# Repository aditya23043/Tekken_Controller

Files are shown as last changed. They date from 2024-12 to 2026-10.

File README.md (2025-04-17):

# One Handed Controller for playing games

- Currently targeting right handed controller and for Tekken because it needs lesser buttons than games like GTA V or CS GO

## Prototype 1

- All files are inside the `prototype_1/` directory

### Shortcomings

- Screw mounting holes are not in the correct place in the bottom plate
- The gap between adjacent switches is not large enough for the keycaps to fit in

### Learnings

- Metal standoffs are enough to hold the top plate rigidly without any visible bending

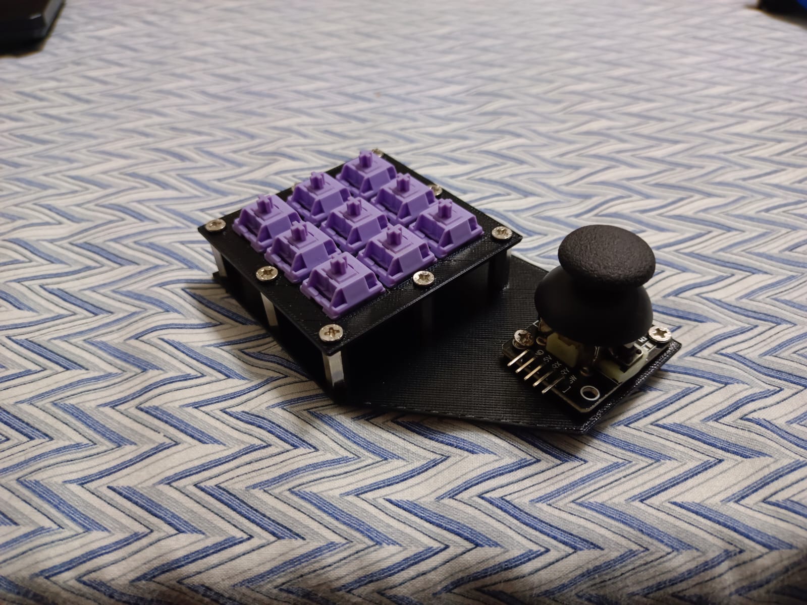
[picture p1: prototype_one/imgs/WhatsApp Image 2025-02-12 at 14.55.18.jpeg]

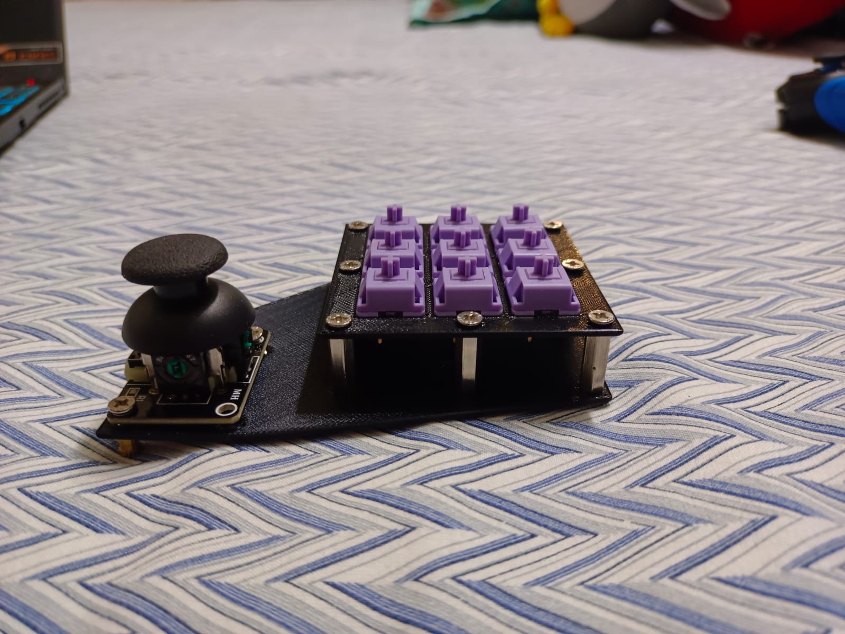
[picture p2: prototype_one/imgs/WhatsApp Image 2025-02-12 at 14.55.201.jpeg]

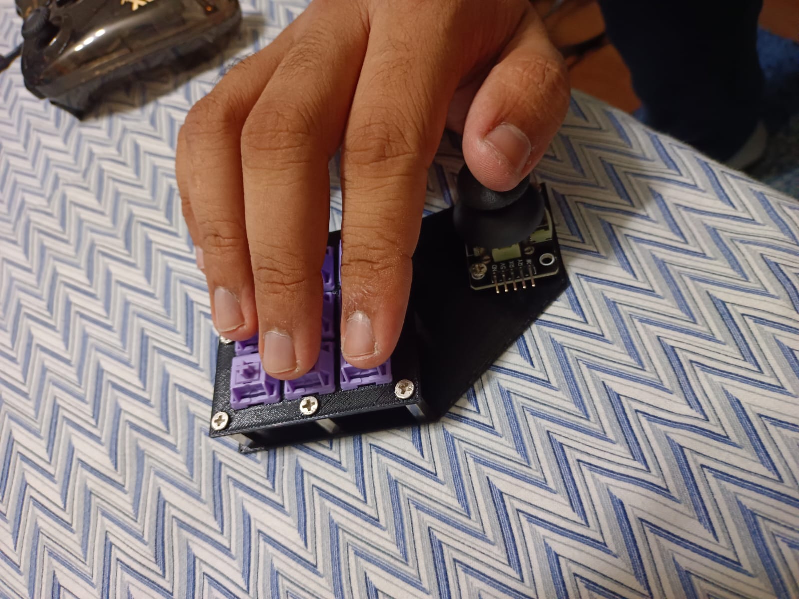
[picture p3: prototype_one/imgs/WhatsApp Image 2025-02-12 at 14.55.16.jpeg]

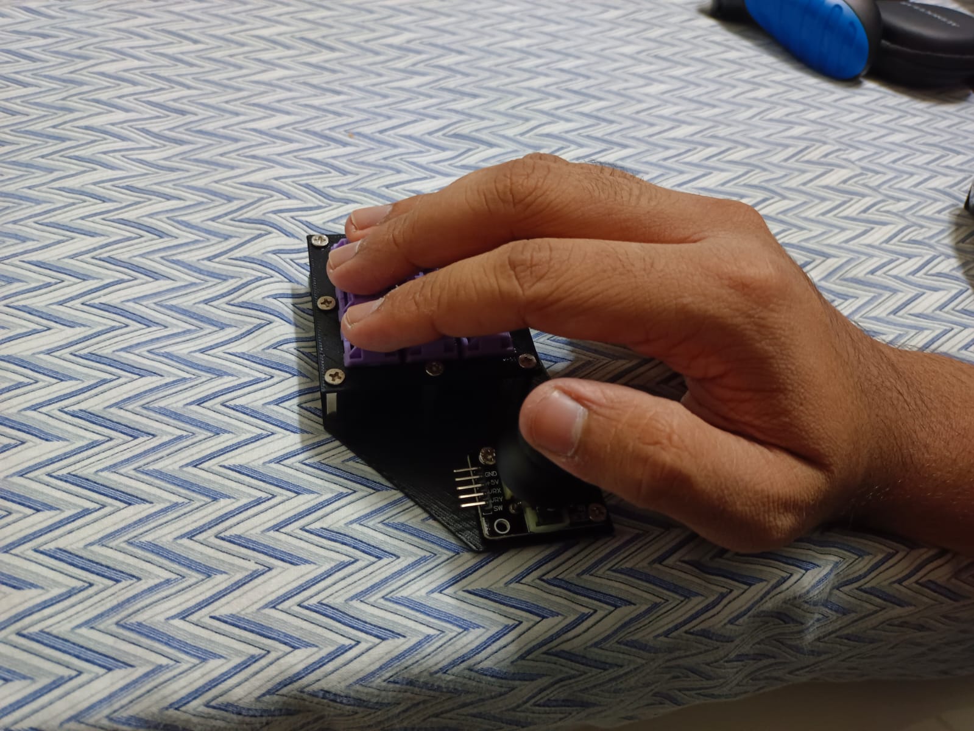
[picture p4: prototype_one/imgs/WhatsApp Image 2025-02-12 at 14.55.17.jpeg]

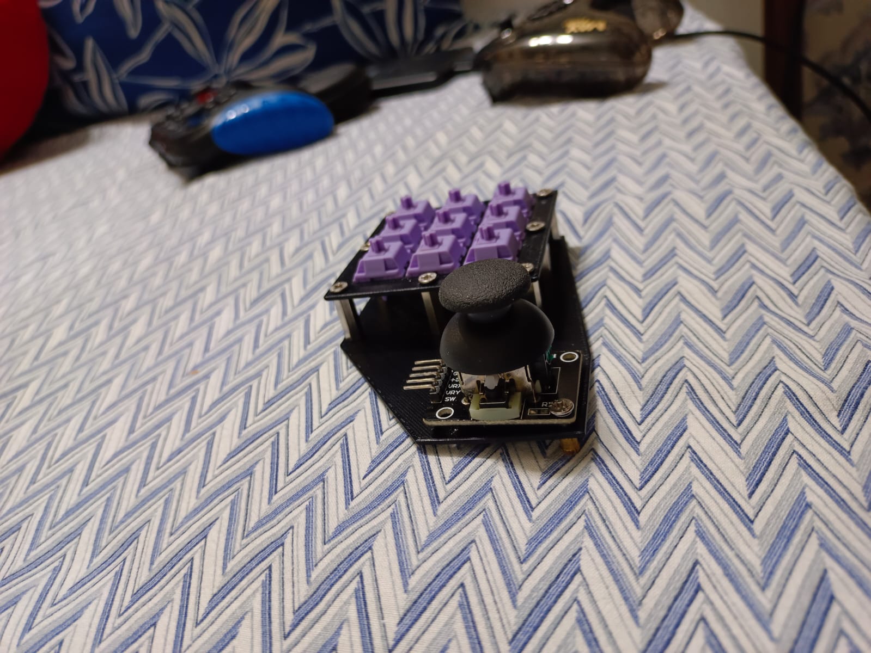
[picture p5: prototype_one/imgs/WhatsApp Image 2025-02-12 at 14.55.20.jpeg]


## Prototype 3

- Switched from a 3x3 switch matrix to a 4x3 switch matrix
- Added dedicated mounting holes for the microcontroller
- Corrected the positioning of the analog joystick and the gap between adjacent MX switches

### Order

- Switch Mount plate : Rs. 74 (PLA - black)
- Bottom Plate - Rs. 122 : PLA - black - 1.5mm - Rs. 149 : Mild Steel - 1mm - Rs. 167 : Mild Steel - 2mm - Rs. 112 : ABS black - 2mm - Rs. 122 : ABS black - 3mm (this is the one I will be ordering) - Rs. 104 : Transparent Acrylic - 2mm - Rs. 263 : Stainless Steel 304 - 1mm

> Note: I have switched the bottom plate a little bit so that a raspberry pi pico could be mounted on the bottom plate so, the price could be a bit skewed, just ~5/6rs

### Final BOM

- Bottom plate -> ABS (non metal laser cut) 3mm -> Rs. 129 + taxes = Rs. 178 (ordered)
- Mount plate -> ABS (PLA 3d printed) -> Rs. 79 + taxes (ordered alongside the single case for -> https://github.com/aditya23043/split36)

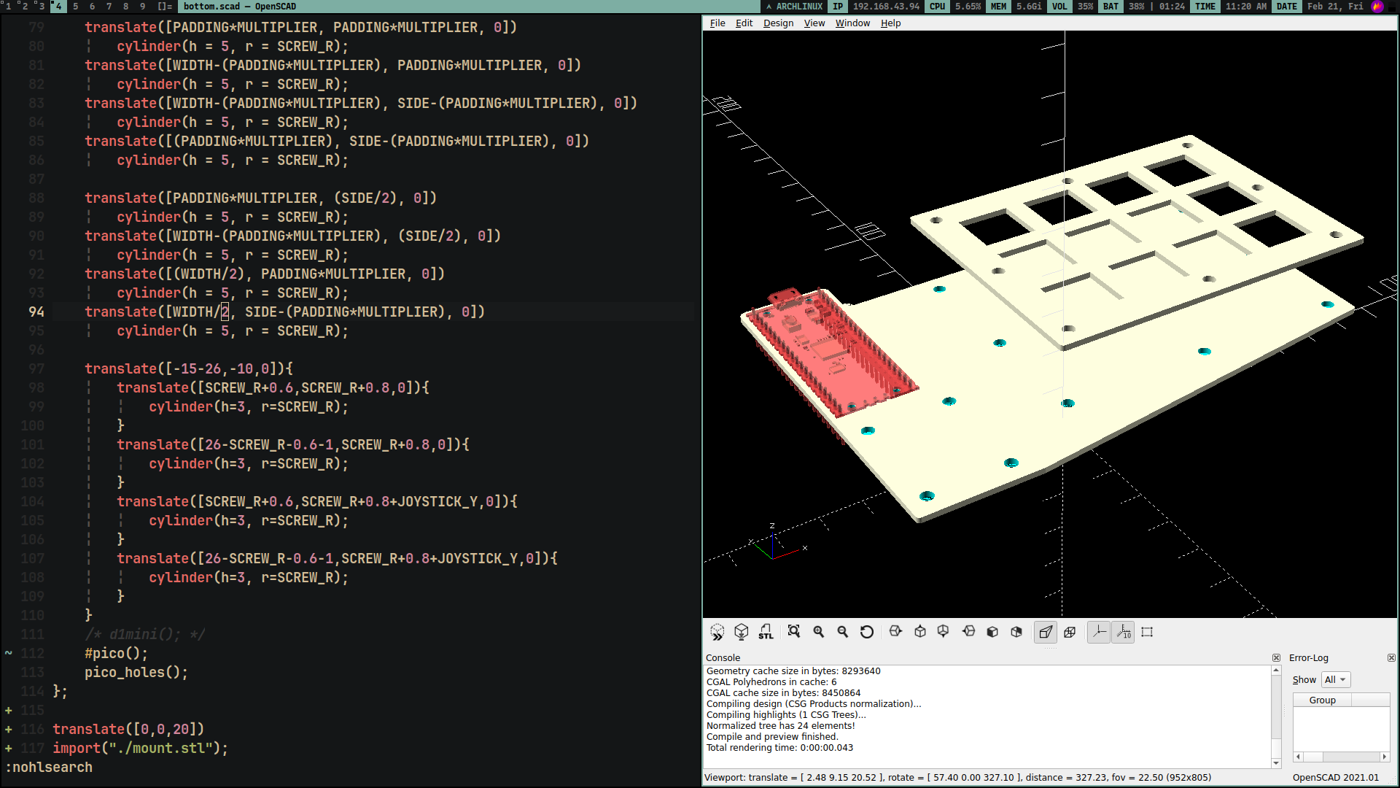
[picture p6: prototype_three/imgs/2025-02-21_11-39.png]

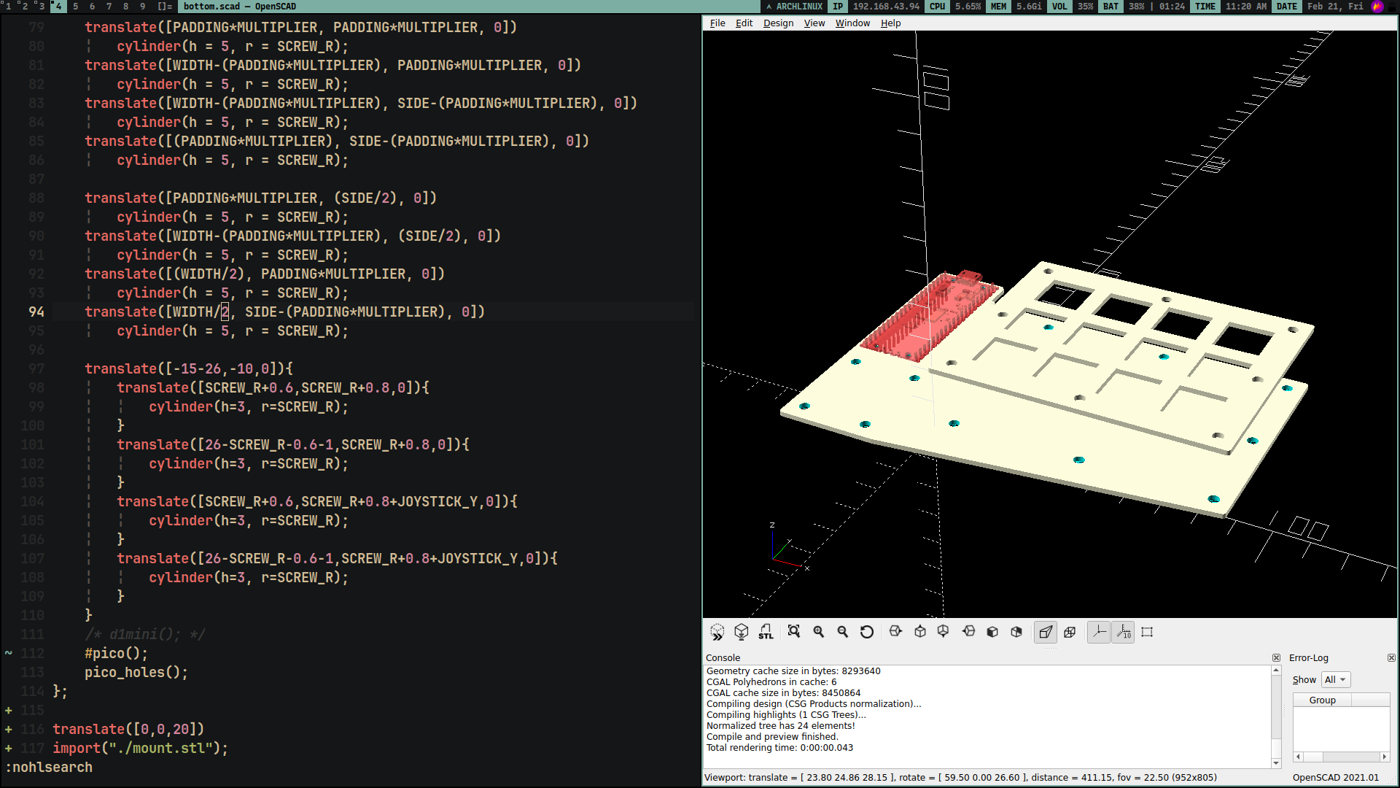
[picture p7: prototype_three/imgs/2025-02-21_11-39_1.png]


### 2025-02-26 23:48

- Finally, all the materials have arrived (I was waiting for the case only. I already had all of the other stuff in my inventory)
- Furthermore, I have assembled all the materials as well

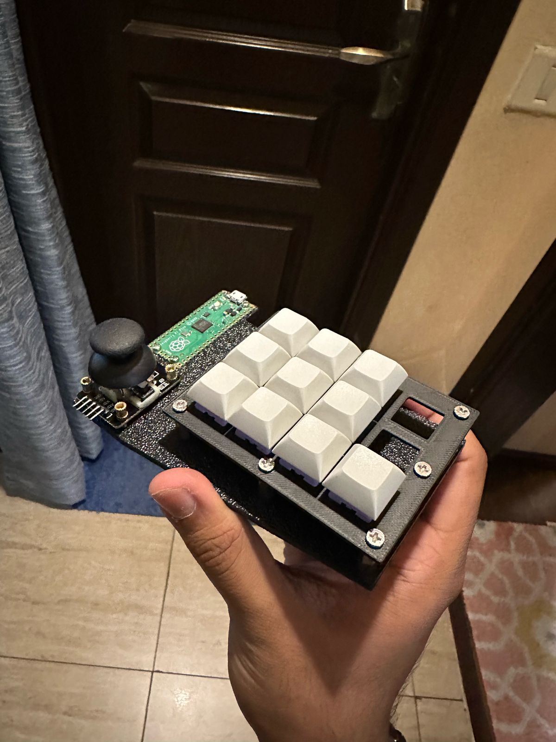
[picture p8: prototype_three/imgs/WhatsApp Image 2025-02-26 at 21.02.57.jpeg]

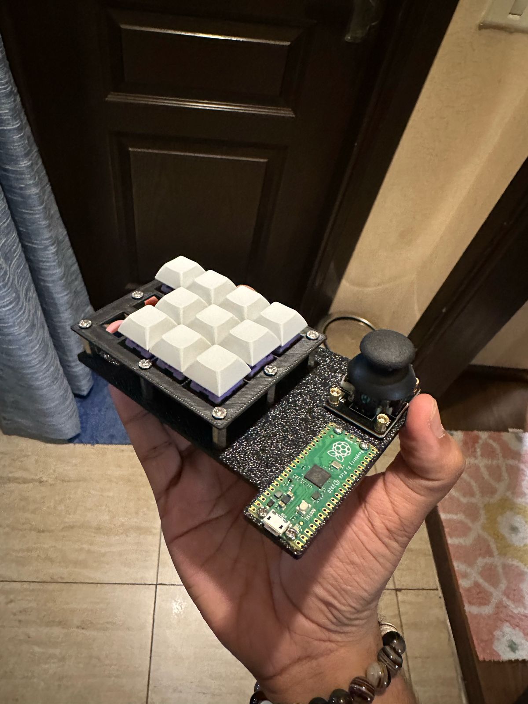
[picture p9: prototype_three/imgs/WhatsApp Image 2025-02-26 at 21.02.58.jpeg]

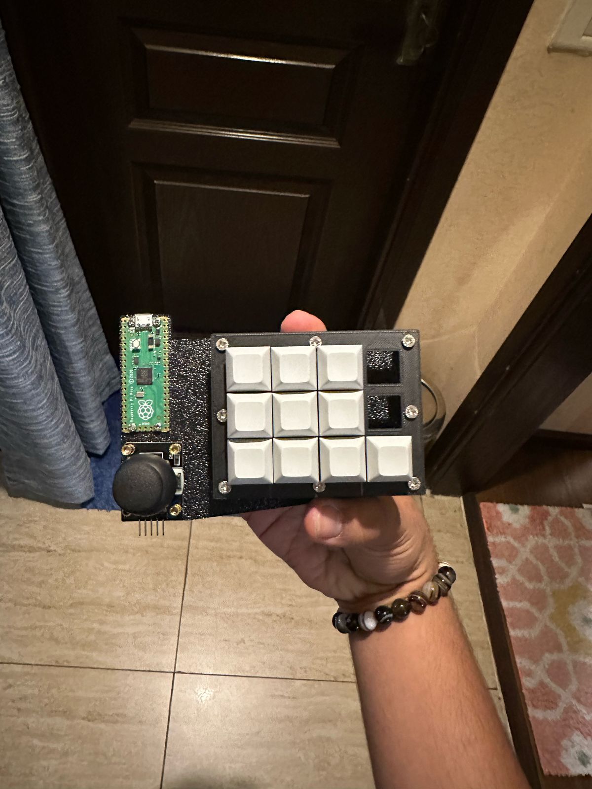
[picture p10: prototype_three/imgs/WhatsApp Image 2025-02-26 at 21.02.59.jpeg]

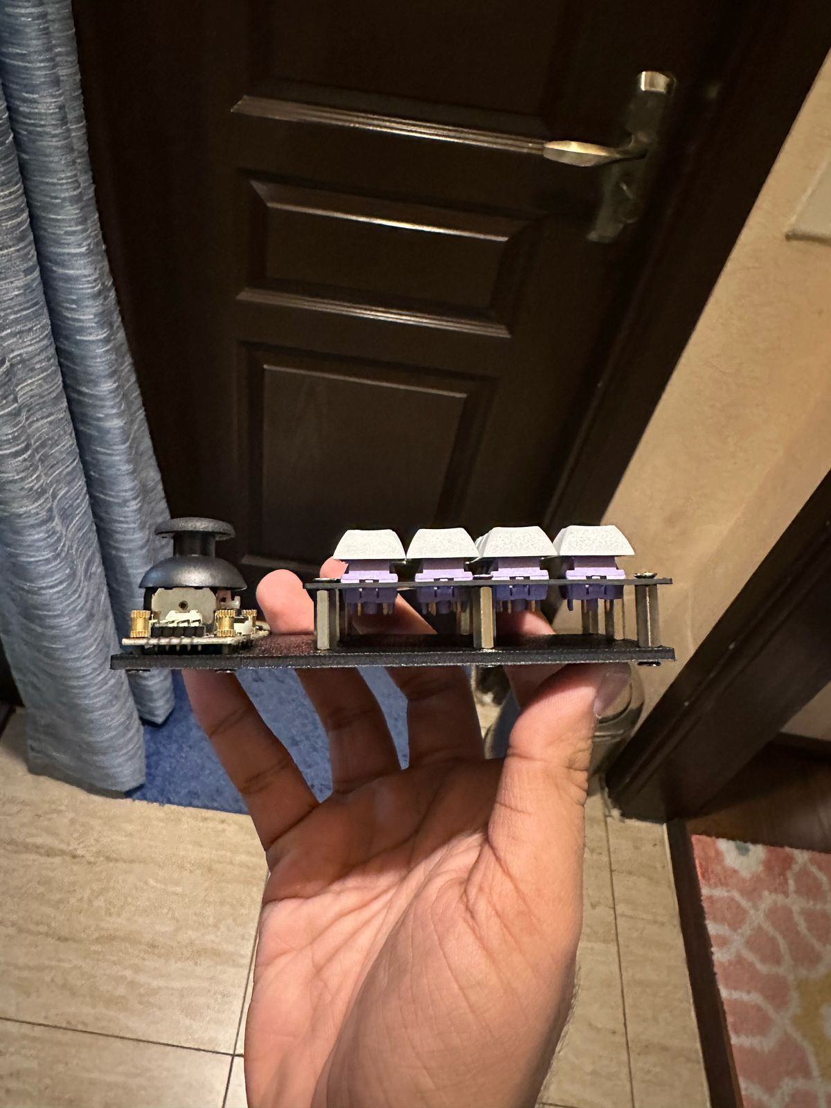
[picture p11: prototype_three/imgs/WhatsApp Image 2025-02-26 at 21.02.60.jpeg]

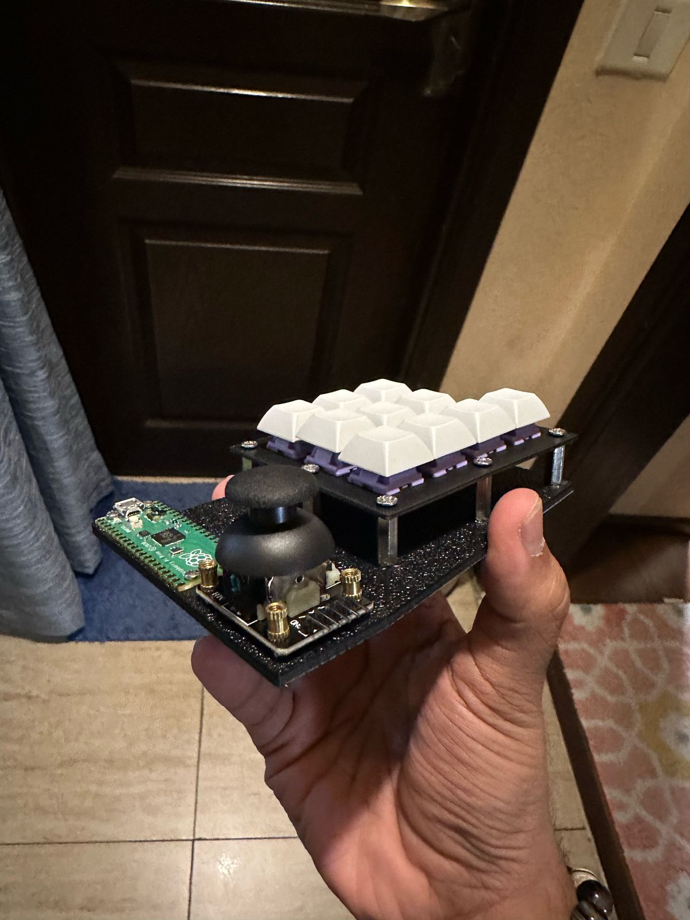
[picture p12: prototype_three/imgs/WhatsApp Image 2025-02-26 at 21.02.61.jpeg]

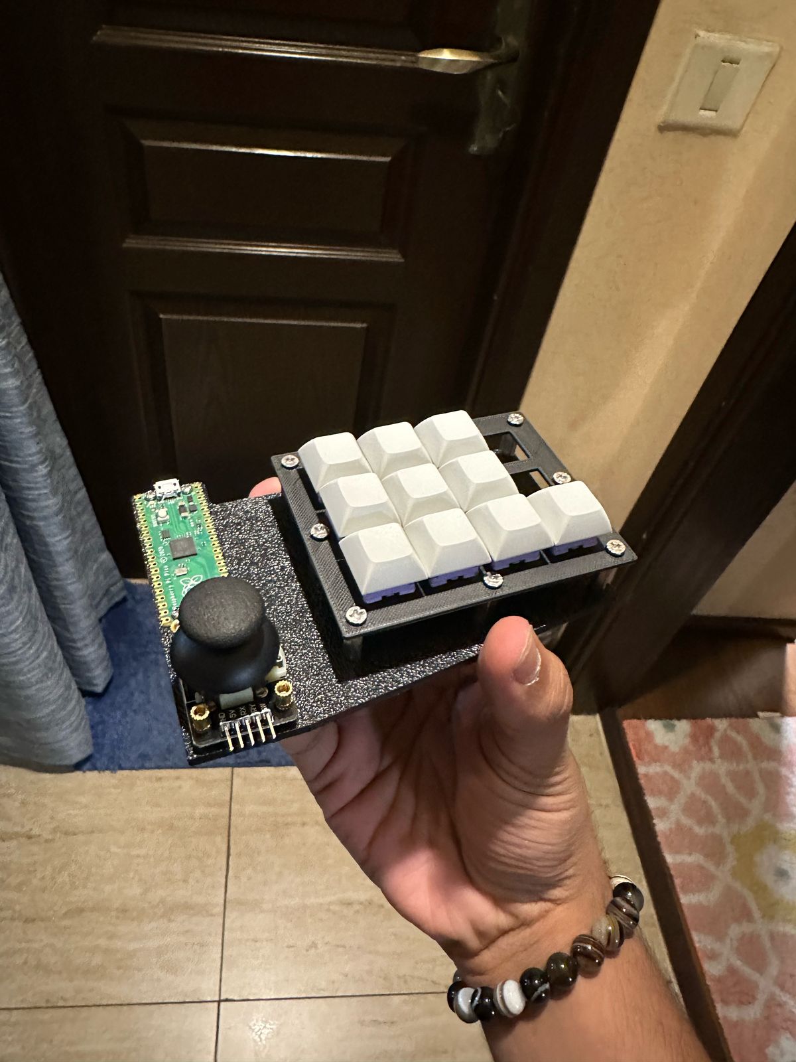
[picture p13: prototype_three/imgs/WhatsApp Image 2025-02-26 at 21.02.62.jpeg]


> Note that you only see 10 out of the 12 switches attached because I only had these 10 switches laying around from my HMX hyacinth V2U collection. The rest 20 were placed in the [20 Key Split Keyboard](https://github.com/aditya23043/split_keyboard) out of the 30 I had ordered

- Since two of my mid semester exams are still remaining (PSD and F&W), I will be waiting for them to get over before beginning with the firmware

### 2025-04-18 00:16
- Wiring and all of the hardware part completed
- Firmware development begins from tomorrow
- [ ] Todo: I would like to add some kind of combination of keys to switch to different keymaps corresponding to different gammes

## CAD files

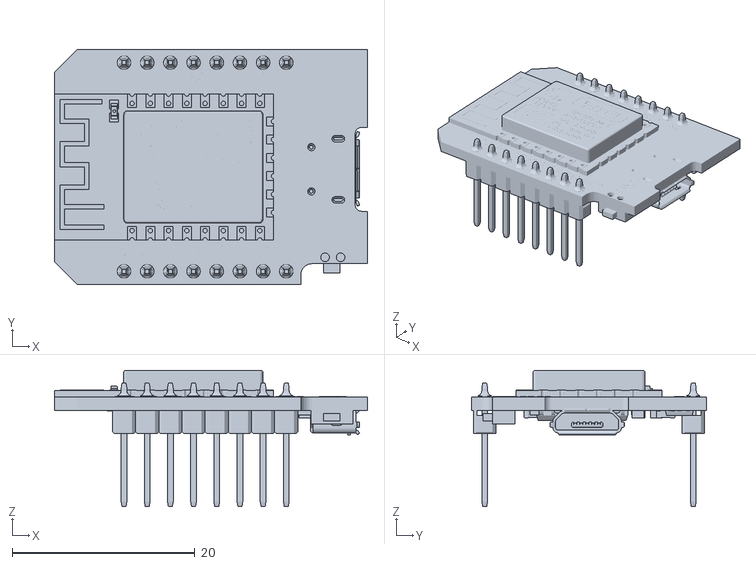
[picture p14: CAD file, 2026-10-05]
prototype_three/WEMOS-MINI-D1_ASM (Meshed).stl
34.3 x 25.8 x 14.9

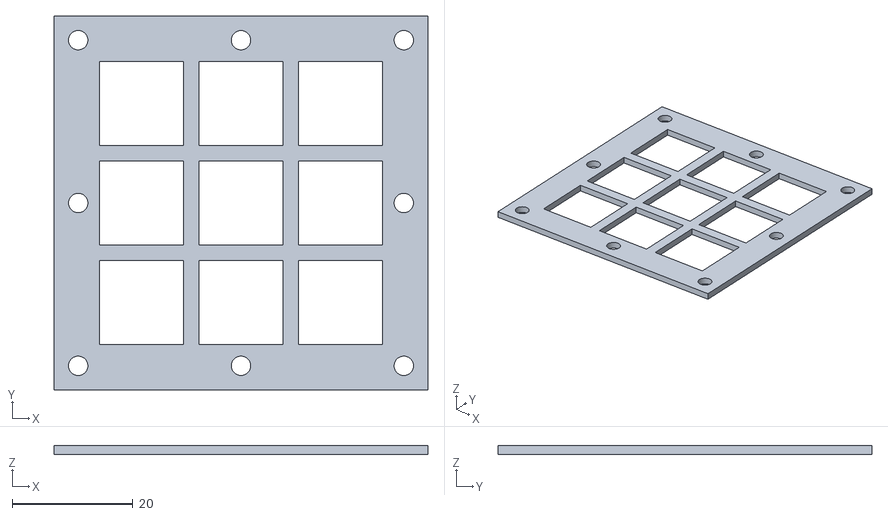
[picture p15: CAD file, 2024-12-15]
prototype_one/top.stl
61.8 x 61.8 x 1.50

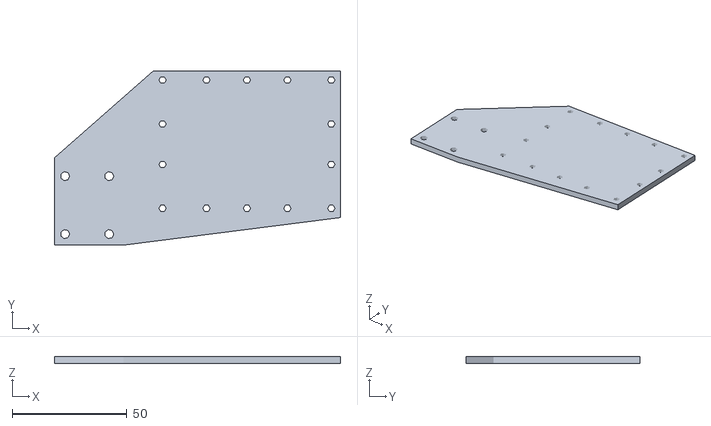
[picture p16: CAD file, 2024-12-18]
prototype_two/bottom.stl
124.4 x 75.8 x 3.00

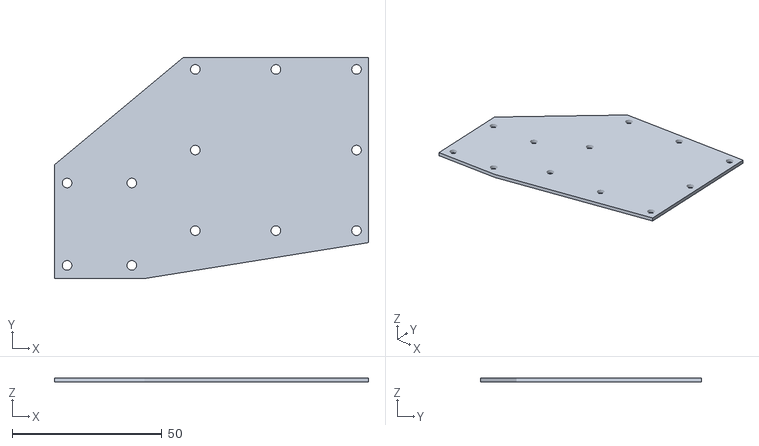
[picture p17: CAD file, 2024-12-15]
prototype_one/bottom.stl
104.8 x 73.8 x 1.50

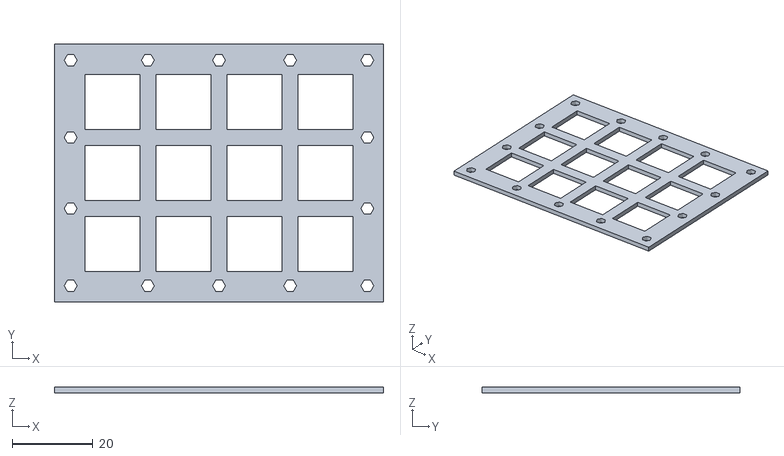
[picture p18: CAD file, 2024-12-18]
prototype_two/top.stl
81.4 x 63.8 x 1.50

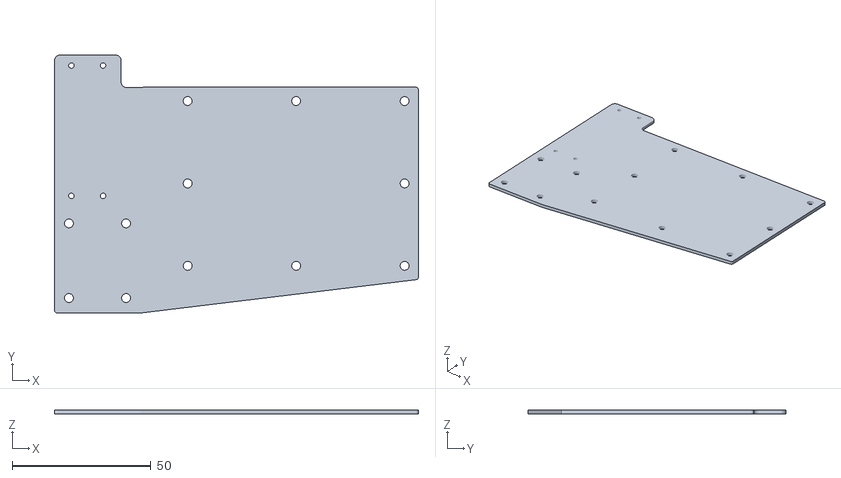
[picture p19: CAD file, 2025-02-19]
prototype_three/bottom_with_pico.stl
131.2 x 93.0 x 1.50

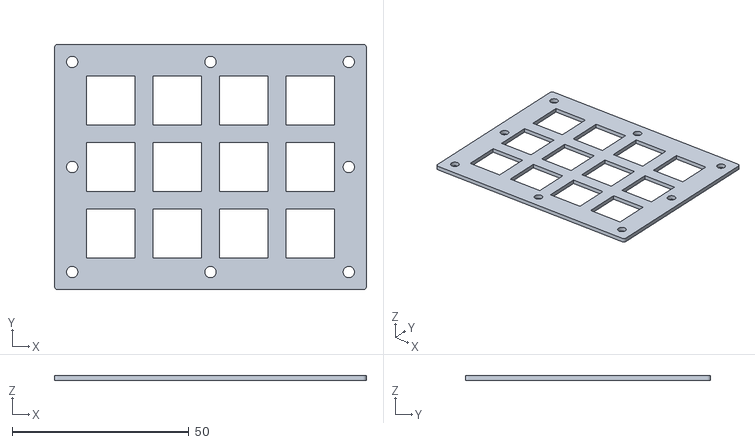
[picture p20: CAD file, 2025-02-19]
prototype_three/mount.stl
88.2 x 69.4 x 1.50

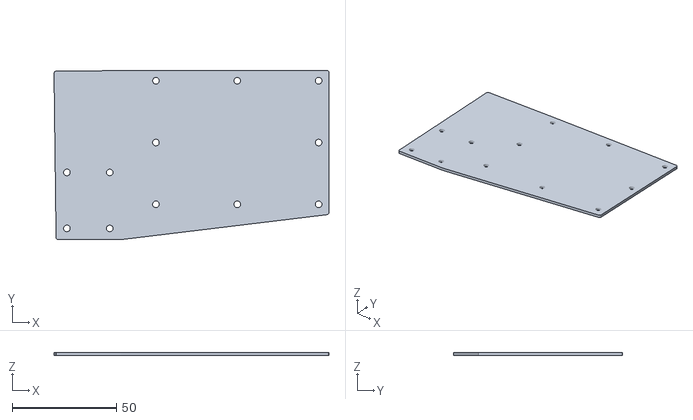
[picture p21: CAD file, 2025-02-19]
prototype_three/bottom.stl
132.2 x 81.4 x 1.50

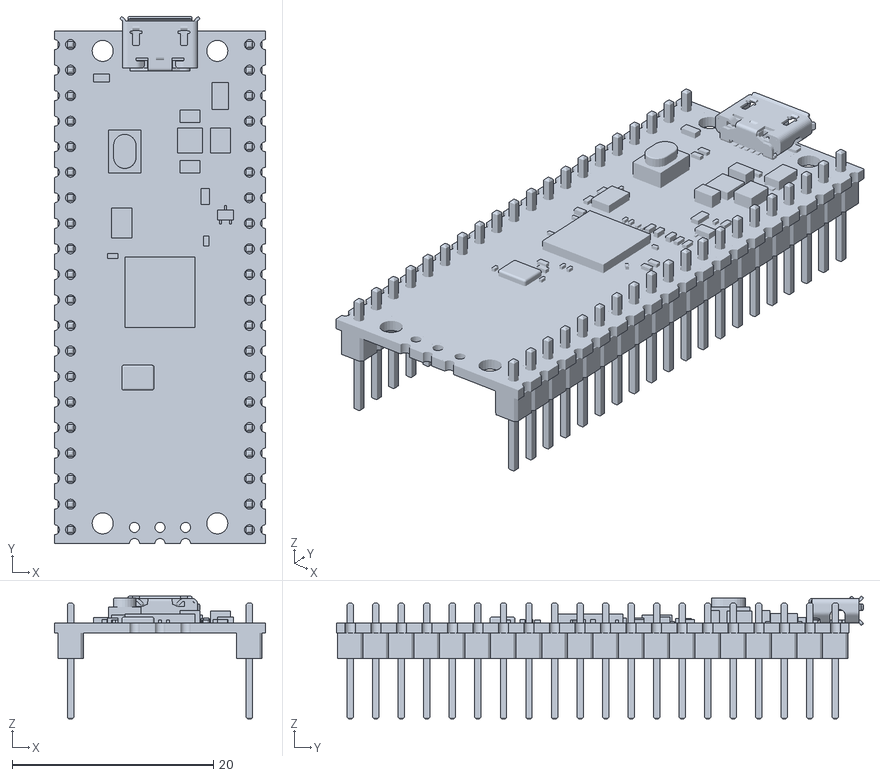
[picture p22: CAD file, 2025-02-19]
prototype_three/rpi.stl
21.0 x 52.4 x 12.2

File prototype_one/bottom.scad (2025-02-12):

SIDE = 51.82;
PAD = 2.53;
SWITCH = 13.9;
PADDING = 10;
SCREW_R = 1.6;
$fn=100;

// total padding = 2.53+5

/* linear_extrude(1.5) */

difference(){

	hull(){
		square([SIDE+PADDING, SIDE+PADDING]);
		translate([-2-15-26,-2-10,0]){
			square([26+4, 34+4]);
		}
	}

	#translate([4,4,0]){
		circle(r=SCREW_R);
	}
	translate([SIDE+PADDING-4,4,0]){
		circle(r=SCREW_R);
	}
	translate([4,SIDE+PADDING-4,0]){
		circle(r=SCREW_R);
	}
	translate([SIDE+PADDING-4,SIDE+PADDING-4,0]){
		circle(r=SCREW_R);
	}
	#translate([4, (SIDE+PADDING)/2, 0]){
		circle(r=SCREW_R);
	}
	translate([SIDE+PADDING-4, (SIDE+PADDING)/2, 0]){
		circle(r=SCREW_R);
	}
	translate([(SIDE+PADDING)/2, 4, 0]){
		circle(r=SCREW_R);
	}
	translate([(SIDE+PADDING)/2, SIDE+PADDING-4, 0]){
		circle(r=SCREW_R);
	}

	translate([-15-26,-10,0]){
		translate([SCREW_R+0.6,SCREW_R+0.8,0]){
			circle(r=SCREW_R);
		}
		translate([26-SCREW_R-0.6,SCREW_R+0.8,0]){
			circle(r=SCREW_R);
		}
		translate([SCREW_R+0.6,34-SCREW_R-2.5,0]){
			circle(r=SCREW_R);
		}
		translate([26-SCREW_R-0.6,34-SCREW_R-2.5,0]){
			circle(r=SCREW_R);
		}
	}
}

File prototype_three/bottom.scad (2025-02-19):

$fn=100;

SCREW_R = 1.6;
PADDING = 8;
MX_SIDE = 13.8;
MX_GAP = 5;
SIDE = (2*PADDING)+(3*MX_SIDE)+(2*MX_GAP);
WIDTH = SIDE + MX_GAP + MX_SIDE;
MULTIPLIER = 0.5;
JOYSTICK_Y = ((51.82+10) / 2)-4;

module d1mini() {
    color("#ffffff")
    rotate([0,0,90])
    translate([50,22,5])
    #import("WEMOS-MINI-D1_ASM (Meshed).stl");
}

module pico(){
    color("#ffffff")
    translate([-128,100,-3])
    import("rpi.stl");
}

module pico_holes(){
    translate([-29.9-8,29.2,0])
            cylinder(r=1,h=2);
    translate([-18.5-8,29.2,0])
            cylinder(r=1,h=2);
    translate([-29.9-8,76.2,0])
            cylinder(r=1,h=2);
    translate([-18.5-8,76.2,0])
            cylinder(r=1,h=2);
}

// projection()
difference(){
    
    union(){
        hull(){
            minkowski(){
                cube([WIDTH, SIDE, 1.4]);
                cylinder(r=1, h=0.1);
            }
            minkowski(){
                linear_extrude(1.4)
                translate([-2-15-26,-2-10,0]){
                    square([26+4, 34+4]);
                }
                cylinder(r=1, h=0.1);
            }
            translate([-44,66.3,0])
                cube([2,2,1.5]);
                /* cylinder(r=1,h=1.5); */
        }
        minkowski(){
            translate([-43+1,68,0])
                cube([10+10+1-1, 10, 1.4]);
            cylinder(r=2,h=0.1);
        }
        
        intersection(){

            difference(){
                translate([-18,70.3,0])
                    translate([-2,-2,0])
                    cube([4,4,1.5]);
                translate([-18,70.3,0])
                    cylinder(h=1.5,r=2);
            };
            translate([-2,-2,0])
                translate([-18,70.3,0])
                cylinder(h=1.5,r=2);
        };

    };

    // screw holes
    translate([PADDING*MULTIPLIER, PADDING*MULTIPLIER, 0])
        cylinder(h = 5, r = SCREW_R);
    translate([WIDTH-(PADDING*MULTIPLIER), PADDING*MULTIPLIER, 0])
        cylinder(h = 5, r = SCREW_R);
    translate([WIDTH-(PADDING*MULTIPLIER), SIDE-(PADDING*MULTIPLIER), 0])
        cylinder(h = 5, r = SCREW_R);
    translate([(PADDING*MULTIPLIER), SIDE-(PADDING*MULTIPLIER), 0])
        cylinder(h = 5, r = SCREW_R);

    translate([PADDING*MULTIPLIER, (SIDE/2), 0])
        cylinder(h = 5, r = SCREW_R);
    translate([WIDTH-(PADDING*MULTIPLIER), (SIDE/2), 0])
        cylinder(h = 5, r = SCREW_R);
    translate([(WIDTH/2), PADDING*MULTIPLIER, 0])
        cylinder(h = 5, r = SCREW_R);
    translate([WIDTH/2, SIDE-(PADDING*MULTIPLIER), 0])
        cylinder(h = 5, r = SCREW_R);

    translate([-15-26,-10,0]){
        translate([SCREW_R+0.6,SCREW_R+0.8,0]){
            cylinder(h=3, r=SCREW_R);
        }
        translate([26-SCREW_R-0.6-1,SCREW_R+0.8,0]){
            cylinder(h=3, r=SCREW_R);
        }
        translate([SCREW_R+0.6,SCREW_R+0.8+JOYSTICK_Y,0]){
            cylinder(h=3, r=SCREW_R);
        }
        translate([26-SCREW_R-0.6-1,SCREW_R+0.8+JOYSTICK_Y,0]){
            cylinder(h=3, r=SCREW_R);
        }
    }
    /* d1mini(); */
    /* #pico(); */
    pico_holes();
};

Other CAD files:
prototype_three/wemos-mini-d1.stp
prototype_three/wemos.stl
prototype_one/top.scad
prototype_three/mount.scad
prototype_one/bottom.dxf
prototype_three/bottom.dxf
prototype_three/bottom_with_pico.dxf
prototype_two/bottom.dxf
prototype_two/bottom.scad
prototype_two/top.scad

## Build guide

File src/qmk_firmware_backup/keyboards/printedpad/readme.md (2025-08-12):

# Printed Pad

magtray4x3

* Keyboard Maintainer: [noahbei](https://github.com/noahbei)
* Hardware Supported: STM32F072RBT6
* Hardware Availability: https://protadesigns.com/products/printed-pad

Make example for this keyboard (after setting up your build environment):

    make printedpad:default

Flashing example for this keyboard:

    make printedpad:default:flash

See the [build environment setup](https://docs.qmk.fm/#/getting_started_build_tools) and the [make instructions](https://docs.qmk.fm/#/getting_started_make_guide) for more information. Brand new to QMK? Start with our [Complete Newbs Guide](https://docs.qmk.fm/#/newbs).

## Bootloader

Enter the bootloader in 3 ways:

* **Bootmagic reset**: Hold down the key at (0,0) in the matrix (usually the top left key or Escape) and plug in the keyboard
* **Physical reset button**: Briefly press the button on the back of the PCB - some may have pads you must short instead
* **Keycode in layout**: Press the key mapped to `QK_BOOT` if it is available

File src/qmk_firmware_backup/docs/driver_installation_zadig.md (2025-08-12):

# Bootloader Driver Installation with Zadig

QMK presents itself to the host as a regular HID keyboard device, and as such requires no special drivers. However, in order to flash your keyboard on Windows, the bootloader device that appears when you reset the board often *does*.

There are two notable exceptions: the Caterina bootloader, usually seen on Pro Micros, and the HalfKay bootloader shipped with PJRC Teensys, appear as a serial port and a generic HID device respectively, and so do not require a driver.

We recommend the use of the [Zadig](https://zadig.akeo.ie/) utility. If you have set up the development environment with MSYS2, the `qmk_install.sh` script will have already installed the drivers for you.

## Installation

Put your keyboard into bootloader mode, either by hitting the `QK_BOOT` keycode (which may be on a different layer), or by pressing the reset switch that's usually located on the underside of the board. If your keyboard has neither, try holding Escape or Space+`B` as you plug it in (see the [Bootmagic](features/bootmagic) docs for more details). Some boards use [Command](features/command) instead of Bootmagic; in this case, you can enter bootloader mode by hitting Left Shift+Right Shift+`B` or Left Shift+Right Shift+Escape at any point while the keyboard is plugged in.
Some keyboards may have specific instructions for entering the bootloader. For example, the [Bootmagic](features/bootmagic) key (default: Escape) might be on a different key, e.g. Left Control; or the magic combination for Command (default: Left Shift+Right Shift) might require you to hold something else, e.g. Left Control+Right Control. Refer to the board's README file if you are unsure.

To put a device in bootloader mode with USBaspLoader, tap the `RESET` button while holding down the `BOOT` button.
Alternatively, hold `BOOT` while inserting the USB cable.

Zadig should automatically detect the bootloader device, but you may sometimes need to check **Options → List All Devices** and select the device from the dropdown instead.

::: warning
If Zadig lists one or more devices with the `HidUsb` driver, your keyboard is probably not in bootloader mode. The arrow will be colored orange and you will be asked to confirm modifying a system driver. **Do not** proceed if this is the case!
:::

If the arrow appears green, select the driver, and click **Install Driver**. See the [list of known bootloaders](#list-of-known-bootloaders) for the correct driver to install.

Zadig with a bootloader driver correctly installed

Finally, unplug and replug the keyboard to make sure the new driver has been loaded. If you are using the QMK Toolbox to flash, exit and restart it too, as it can sometimes fail to recognize the driver change.

## Recovering from Installation to Wrong Device

If you find that you can no longer type with the keyboard, you may have accidentally replaced the driver for the keyboard itself instead of for the bootloader. This can happen when the keyboard is not in the bootloader mode. You can easily confirm this in Zadig - a healthy keyboard has the `HidUsb` driver installed on all of its interfaces:

A healthy keyboard as seen by Zadig

Open the Device Manager, select **View → Devices by container**, and look for an entry with your keyboard's name.

The board with the wrong driver installed, in Device Manager

Right-click each entry and hit **Uninstall device**. Make sure to tick **Delete the driver software for this device** first if it appears.

The Device Uninstall dialog, with the "delete driver" checkbox ticked

Click **Action → Scan for hardware changes**. At this point, you should be able to type again. Double check in Zadig that the keyboard device(s) are using the `HidUsb` driver. If so, you're all done, and your board should be functional again! Otherwise, repeat this process until Zadig reports the correct driver.

::: tip
A full reboot of your computer may sometimes be necessary at this point, to get Windows to pick up the new driver.
:::

## Uninstallation

Uninstallation of bootloader devices is a little more involved than installation.

Open the Device Manager, select **View → Devices by container**, and look for the bootloader device. Match up the USB VID and PID in Zadig with one from [the table below](#list-of-known-bootloaders).

Find the `Inf name` value in the Details tab of the device properties. This should generally be something like `oemXX.inf`:

Device properties showing the Inf name value

Then, open a new Command Prompt window as an Administrator (type in `cmd` into the Start menu and press Ctrl+Shift+Enter). Run `pnputil /enum-drivers` to verify the `Inf name` matches the `Published Name` field of one of the entries:

pnputil output with matching driver highlighted

Run `pnputil /delete-driver oemXX.inf /uninstall`. This will delete the driver and remove it from any devices using it. Note that this will not uninstall the device itself.

As with the previous section, this process may need to be repeated multiple times, as multiple drivers can be applicable to the same device.

::: warning
Be *extremely careful* when doing this! You could potentially uninstall the driver for some other critical device. If you are unsure, double check the output of `/enum-drivers`, and omit the `/uninstall` flag when running `/delete-driver`.
:::

## List of Known Bootloaders

This is a list of known bootloader devices and their USB vendor and product IDs, as well as the correct driver to assign for flashing with QMK. Note that the usbser and HidUsb drivers are built in to Windows, and cannot be assigned with Zadig - if your device has an incorrect driver, you must use the Device Manager to uninstall it as described in the previous section.

The device name here is the name that appears in Zadig, and may not be what the Device Manager or QMK Toolbox displays.

|Bootloader |Device Name |VID/PID |Driver |
|---|---|---|---|
|`atmel-dfu` |ATmega16u2 DFU |`03EB:2FEF` |WinUSB |
|`atmel-dfu` |ATmega32U2 DFU |`03EB:2FF0` |WinUSB |
|`atmel-dfu` |ATm16U4 DFU V1.0.2 |`03EB:2FF3` |WinUSB |
|`atmel-dfu` |ATm32U4DFU |`03EB:2FF4` |WinUSB |
|`atmel-dfu` |*none* (AT90USB64) |`03EB:2FF9` |WinUSB |
|`atmel-dfu` |AT90USB128 DFU |`03EB:2FFB` |WinUSB |
|`qmk-dfu` |(keyboard name) Bootloader |As `atmel-dfu`|WinUSB |
|`halfkay` |*none* |`16C0:0478` |HidUsb |
|`caterina` |Pro Micro 3.3V |`1B4F:9203` |usbser |
|`caterina` |Pro Micro 5V |`1B4F:9205` |usbser |
|`caterina` |LilyPadUSB |`1B4F:9207` |usbser |
|`caterina` |Pololu A-Star 32U4 Bootloader |`1FFB:0101` |usbser |
|`caterina` |Arduino Leonardo |`2341:0036` |usbser |
|`caterina` |Arduino Micro |`2341:0037` |usbser |
|`caterina` |Adafruit Feather 32u4 |`239A:000C` |usbser |
|`caterina` |Adafruit ItsyBitsy 32u4 3V |`239A:000D` |usbser |
|`caterina` |Adafruit ItsyBitsy 32u4 5V |`239A:000E` |usbser |
|`caterina` |Arduino Leonardo |`2A03:0036` |usbser |
|`caterina` |Arduino Micro |`2A03:0037` |usbser |
|`bootloadhid` |HIDBoot |`16C0:05DF` |HidUsb |
|`usbasploader`|USBasp |`16C0:05DC` |libusbK|
|`apm32-dfu` |APM32 DFU ISP Mode |`314B:0106` |WinUSB |
|`at32-dfu` |AT32 Bootloader DFU |`2E3C:DF11` |WinUSB |
|`stm32-dfu` |STM32 BOOTLOADER |`0483:DF11` |WinUSB |
|`gd32v-dfu` |GD32V BOOTLOADER |`28E9:0189` |WinUSB |
|`kiibohd` |Kiibohd DFU Bootloader |`1C11:B007` |WinUSB |
|`stm32duino`  |Maple 003 |`1EAF:0003` |WinUSB |
|`qmk-hid` |(keyboard name) Bootloader |`03EB:2067` |HidUsb |

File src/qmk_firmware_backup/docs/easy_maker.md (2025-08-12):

# Easy Maker - Build One-Off Projects In Configurator

Have you ever needed an easy way to program a controller, such as a Proton C or Teensy 2.0, for a one-off project you're building? QMK has you covered with the Easy Maker. Now you can create a firmware in minutes using QMK Configurator.

There are different styles of Easy Maker available depending on your needs:

* [Direct Pin](https://config.qmk.fm/#/?filter=ez_maker/direct) - Connect a single switch to a single pin
* Direct Pin + Backlight (Coming Soon) - Like Direct Pin but dedicates a single pin to [Backlight](features/backlight) control
* Direct Pin + Numlock (Coming Soon) - Like Direct Pin but dedicates a single pin to the Numlock LED
* Direct Pin + Capslock (Coming Soon) - Like Direct Pin but dedicates a single pin to the Capslock LED
* Direct Pin + Encoder (Coming Soon) - Like Direct Pin but uses 2 pins to add a single rotary encoder

## Quickstart

The easiest way to get started is with the Direct Pin boards. This will assign a single key to each pin and you can short that pin to ground to activate it. Select your MCU from the Keyboard dropdown here:

* <https://config.qmk.fm/#/?filter=ez_maker/direct>

For more details see the [Direct Pin](#direct-pin) section.

# Direct Pin

As its name implies Direct Pin works by connecting one switch per pin. The other side of the switch should be connected to ground (VSS or GND.) You don't need any other components, your MCU has internal pull-up resistors so that the switch sensing can work.

Here is a schematic showing how we connect a single button to pin A3 on a ProMicro:

Schematic diagram showing a ProMicro with a wire coming out of A3, connecting to the left side of a switch. Another wire comes out of the right side of the switch to connect to the Ground Plane.

Once you have wired your switches you can assign keycodes to each pin and build a firmware by selecting the MCU you are using from the Keyboard dropdown. Use this link to show only Easy Maker Direct Pin:

* <https://config.qmk.fm/#/?filter=ez_maker/direct>

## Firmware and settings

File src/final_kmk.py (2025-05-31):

import board

from kmk.kmk_keyboard import KMKKeyboard
from kmk.keys import KC
from kmk.scanners.keypad import KeysScanner

from kmk.modules.holdtap import HoldTap, HoldTapRepeat
from kmk.modules.layers import Layers
from kmk.modules.mouse_keys import MouseKeys
from kmk.modules.macros import Macros
from kmk.modules.tapdance import TapDance
from kmk.modules.sticky_keys import StickyKeys

_KEY_CFG = [
    board.GP28,  board.GP17,  board.GP16, board.GP9,
    board.GP22,  board.GP6,  board.GP19, board.GP21,
    board.GP7, board.GP18, board.GP20, board.GP8
]


class MyKeyboard(KMKKeyboard):
    def __init__(self):
        super().__init__()
        self.matrix = KeysScanner(
            pins=_KEY_CFG,
            value_when_pressed=False,
            pull=True,
        )
        self.coord_mapping = [
             0,  1,  2,  3,
             4,  5,  6,  7,
             8,  9, 10, 11,
        ]

keyboard = MyKeyboard()

keyboard.keymap = [

    [
        KC.Q, KC.W, KC.E, KC.R,
        KC.A, KC.S, KC.D, KC.F,
        KC.Z, KC.X, KC.C, KC.V,
    ]

]

if __name__ == '__main__':
    keyboard.go()

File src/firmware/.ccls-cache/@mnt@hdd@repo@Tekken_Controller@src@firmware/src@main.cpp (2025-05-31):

#include <Arduino.h>
#include <USBMouseKeyboard.h>

/*
28 27 26 09
22 06 19 21
07 18 20 08
*/

const int VRX = 27;
const int VRY = 26;
const int SW = 14;

const int pins[] = {28, 27, 26, 9, 22, 6, 19, 21, 7, 18, 20, 8};
const char mapping[] = {};

const int sensitivity = 5;

USBMouseKeyboard key_mouse;

void setup() {
  pinMode(LED_BUILTIN, OUTPUT);
  pinMode(SW, INPUT_PULLUP);
}

void loop() {

  int x_value = analogRead(VRX);
  int y_value = analogRead(VRY);
  int button = digitalRead(SW);

  if (y_value == 5) {
    key_mouse.move(0, -1 * sensitivity);
  } else if (y_value < 400) {
    key_mouse.move(0, -1 * (sensitivity - 3));
  }
  if (y_value == 1023) {
    key_mouse.move(0, sensitivity);
  } else if (y_value > 600) {
    key_mouse.move(0, (sensitivity - 3));
  }

  if (x_value == 5) {
    key_mouse.move(sensitivity, 0);
  } else if (x_value < 400) {
    key_mouse.move((sensitivity - 3), 0);
  }

  if (x_value == 1023) {
    key_mouse.move(-1 * sensitivity, 0);
  } else if (x_value > 600) {
    key_mouse.move(-1 * (sensitivity - 3), 0);
  }

  if (button == LOW) {
    key_mouse.click(MOUSE_LEFT);
  }

  delay(10);
}

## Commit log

2024-12-15 pushed stl files
    [bottom.dxf, bottom.scad, bottom.stl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]
2024-12-15 bom updated
2024-12-18 refactored directory structure and added prototype dirs
    [bottom.dxf, bottom.scad, bottom.stl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]
2024-12-18 dimensions fixed and prototype 2 done
    [bottom.dxf, bottom.scad, bottom.stl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]
2025-02-12 added photos of the first prototype
2025-02-12 readme updated
    [bottom.dxf, bottom.scad, bottom.stl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]
2025-02-19 almost done with the case / enclosure
    [bottom.scad, bottom.stl, mount.stl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]
2025-02-19 modified bottom stl to include mount holes for raspberry pi pico
    [bottom.scad, bottom_with_pico.stl]
2025-02-19 BOM written in readme
    [bottom_with_pico.dxf]
2025-02-21 case openscad screenshots added
2025-02-21 added the improvements of the 2nd prototype to README
2025-04-17 soldering done
2025-08-12 bunch of firmwares pushed
    [nose2.cfg]
2026-10-05 firmware pushed
    [WEMOS-MINI-D1_ASM (Meshed).stl, bottom.dxf, bottom.scad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]
